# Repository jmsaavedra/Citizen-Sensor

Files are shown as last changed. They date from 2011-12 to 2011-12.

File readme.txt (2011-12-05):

Citizen Sensor

http://citizensensor.cc

DIY environmental and air quality monitoring. Has been developed as both stationary and mobile units. 

Stationary units have been deployed all over world. CS was used in the "weather tunnel" project, exhibited at the national art museum of China, Beijing summer 2011. 

*stationary*
 > operate as stationary units connected to the internet via ethernet cable
 > arduino based
 > require wall power (7-12v DC power brick)
 > use pachube (some units live currently: https://pachube.com/feeds?user=weathertunnel)
 > schematic on Upverter: http://upverter.com/jmsaavedra/634b5640a5bbd8a7/Citizen-Sensor---Stationary-Version-02/

*mobile*
 > operate as bluetooth peripherals for an Android application
 > arduino based
 > battery powered
 > updates output to LAYAR, google maps, and private social networks
 > pachube support coming

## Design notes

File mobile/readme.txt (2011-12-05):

Citizen Sensor

http://citizensensor.cc

DIY environmental and air quality monitoring. Has been developed as both stationary and mobile units. 

*mobile*
 > operate as bluetooth peripheral for an Android application
 > arduino based
 > battery powered
 > updates output to LAYAR, google maps, and private social networks
 > pachube support coming

Arduino + Bluetooth antenna talks to Android phone.  Android phone beams data up to custom server.

coming: - schematics / board design
	- Android app
	- arduino compatible circuit code

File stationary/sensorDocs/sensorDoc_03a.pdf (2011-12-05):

Weather

Tunnel

:

Sensor

Data

sheet
>>

Technology

Overview

and

Data

Schematic

Each

Weather

Tunnel

collaborator

will

be

setting

up

their

own

local

data

collection
‘node’,

feeding

and

sharing

local

environmental

data

for

use

by

all

other

institutions.
In

order

to

do

this,

we’ll

be

utilizing

custom

hardware

and

software.

This

document
will

provide

an

overview

as

to

how

we

will

be

capturing,

sharing,

and

accessing

all
data.

Hardware

Each

collaborator

will

receive

a

Weather

Tunnel

sensor

module.

These

boxes

are
meant

to

be

placed

outside,

however

there

are

several

considerations

to

be

made
before

installation.

The

sensor

module

requires

access

to

two

things:

power

(110v
or

220v

is

fine)

and

a

hardline

Ethernet

connection

to

the

internet

with

a

static

IP
address.

Each

module

will

arrive

to

you

pre-‐programmed

to

connect

from

a

specific
IP

address

which

you

will

need

to

identify

(and

share

with

us,

see

‘Identifying

your
IP

Address’)

before

receiving

it.

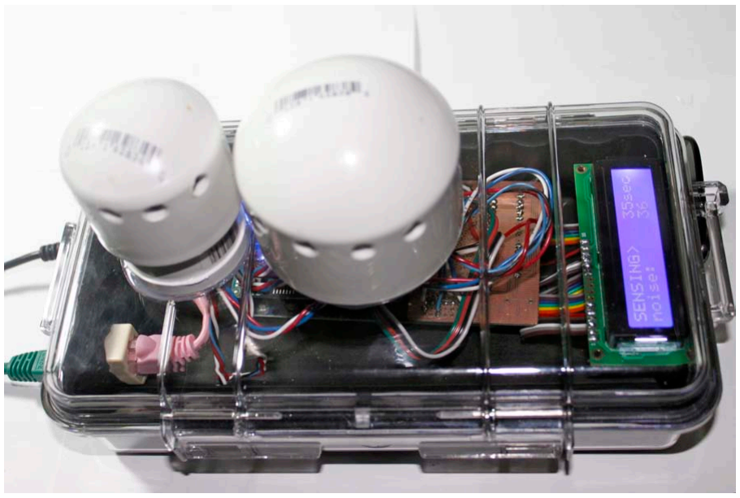
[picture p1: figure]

The

sensor

module

is

designed

to

be

installed

outdoors

and

able

to

survive
moderate

to

medium-‐heavy

rain

in

all

temperatures.

However,

if

it

is

heavily
raining

outside

your

window,

please

feel

free

to

bring

it

inside

for

that

period

of
time.

The

modules

are

outfitted

with

sensors

for

measuring:
-‐ ambient

light
-‐ ambient

sound
-‐ temperature
-‐ humidity
-‐ carbon

monoxide

(CO)
-‐ carbon

dioxide

(CO2)
-‐ general

air

quality

(NOx,

smoke)

The

sensors

themselves

are

located

beneath

two

PVC

dome

shields.

The

smaller
dome

contains

temperature,

humidity,

and

ambient

noise

sensors.

The

light

sensor
is

housed

in

the

body

of

the

module.

The

remaining

gas

sensors

are

located

in

the
larger

dome.

These

are

housed

separately,

as

their

sensing

mechanism

involves
heating

a

gas-‐specific

sensitive

element.

The

heat

could

damage

the

other

sensors,
so

they

have

been

isolated.

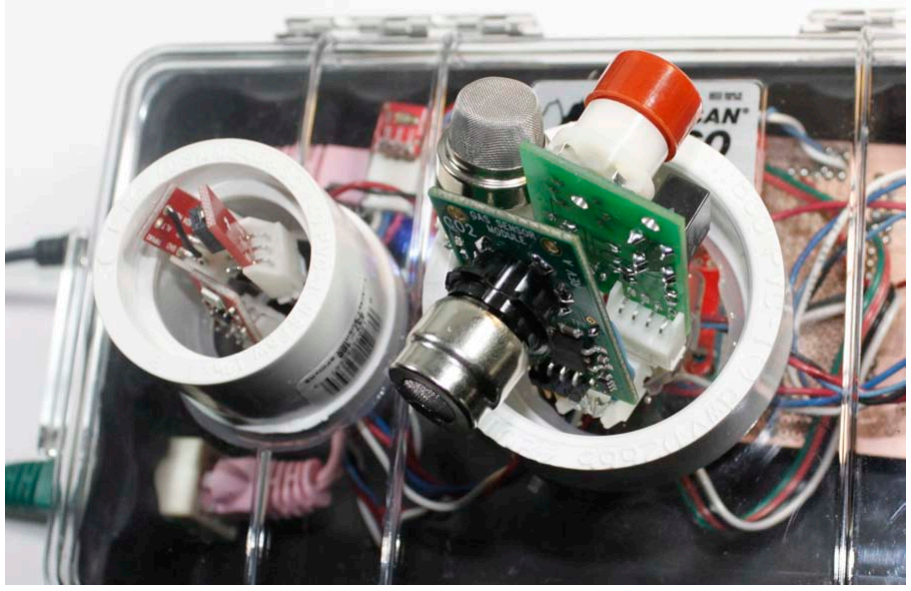
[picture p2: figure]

Each

dome

has

4

holes

for

air

to

enter

and

flow

through.

A

mesh

has

been

adhered
to

the

inside

of

the

holes

to

prevent

large

particles

of

moisture

or

debris

to

enter

the
sensor

housing.

The

domes

are

removable

and

have

not

been

permanently
attached.

This

is

to allow

you

to

rotate

them

as

needed

so

the

holes

point

away

from
your

building,

for

instance.

Setup:

The

modules

have

been

designed

to

be

‘plug

and

play’.

Upon

receiving

yours,
simply

connect

the

Ethernet

cable

(connected

through

the

static

IP

address

you

identified

to

us

when

requesting

your

unit),

and

then

the

power

supply,

which

is
included

in

the

package

you

have

received.

The

unit

will

turn

on

and

immediately
begin

reading

it’s

sensors

and

posting

data

online.

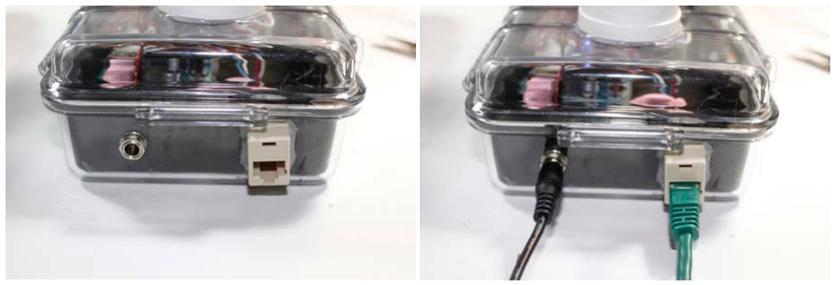
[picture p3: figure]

A

few

notes:

Once

you’ve

begun

posting

data

successfully,

it

will

take

2

–

3

days

for
all

of

your

data

to

‘normalize’.

This

is

because

several

of

the

gas

sensors

using

analog
filaments

for

sensing

pollutants.

They

require

this

amount

of

warm-‐up

time

before
they

are

stabilized.

Be

sure

to

leave

the

unit

powered

at

all

times.

It

is

also

normal
for

the

unit

to

warm

up.

Both

the

gas

sensors

as

well

as

the

body

itself

will

heat

up.
This

is

normal,

do

not

be

alarmed.

LCD

Messages:

Each

unit

is

equipped

with

an

LCD

screen

that

displays

constant
status

messages.

Here

is

a

quick

overview

of

each

message.

Upon

powering

your

unit,

you

will

be

greeted.

An

initialization

sequence

will

follow.
The

initialization

sequence

will

display

the

IP

address,

Subnet

Mask,

and

Gateway
Address

that

have

been

programmed

into

your

specific

unit.

These

must

match

the
addresses

of

the

specific

Ethernet

port

you

have

connected

the

unit

to!

It

will

also
display

your

node’s

specific

Pachube

Feed

ID.

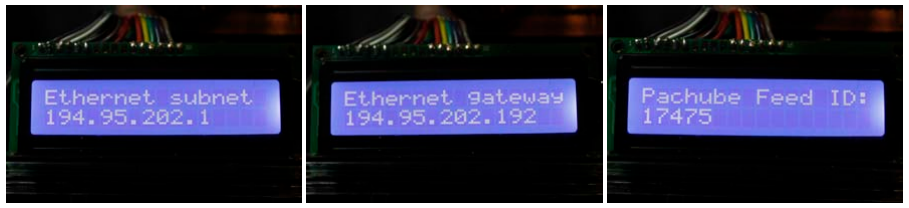
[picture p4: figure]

This

initialization

sequence

will

display

each

time

the

unit

has

been

powered

or
reset.

Following

this

setup,

the

unit

will

begin

reading

data

from

the

sensors.

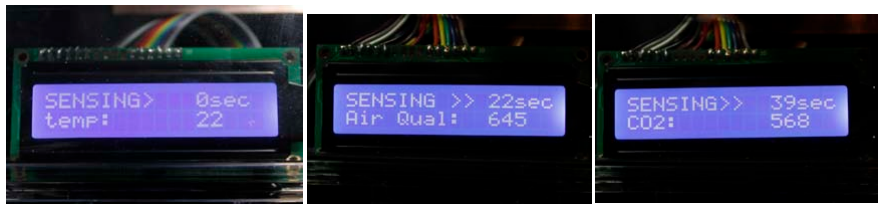
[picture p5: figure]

While

the

unit

is

taking

measurements,

it

will

display

“SENSING

>>”

in

the

top

left
corner.

On

the

right

side

of

the

top

line

is

the

number

of

seconds

that

have

passed
since

the

last

successful

data

upload.

This

number

will

never

go

above

120sec.

On
the

second

line

you’ll

see

the

sensor

being

read

at

that

moment.

To

the

right

of

this,
the

value

of

the

reading

taken

at

that

moment.

During

this

time,

a

blue

LED

will

be
pulsing

on

and

off

letting

you

know

from

a

distance

that

sensors

are

being
measured.

Every

30-‐40

seconds,

the

unit

will

attempt

to

upload

the

latest

readings.

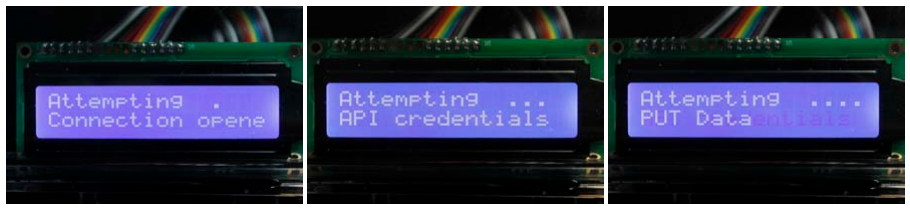
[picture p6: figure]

These

messages

are

mostly

for

debugging

purposes.

The

display

will

update

as

the
unit

goes

through

each

step

of

connecting

to

the

Pachube

server.

If

all

is

well,

these
should

cycle

quickly.

If

the

connection

attempt

was

successful

you

will

see

the
message

“Data

Sent!”

on

the

screen.

The

unit

will

now

return

to

reading

the

sensors.

If

there

were

problems

during

the

upload

process,

you

will

see

the

message
“Connection

Fail

check

IP/subnet/gateway”.

If

the

connection

fails

repeatedly

and
no

successful

upload

has

been

made

in

over

2

minutes,

the

board

will

reset

itself.

If
you

notice

that

the

board

is

never

able

to

connect,

and

simply

resets

itself
repeatedly,

please

read

the

troubleshooting

section.

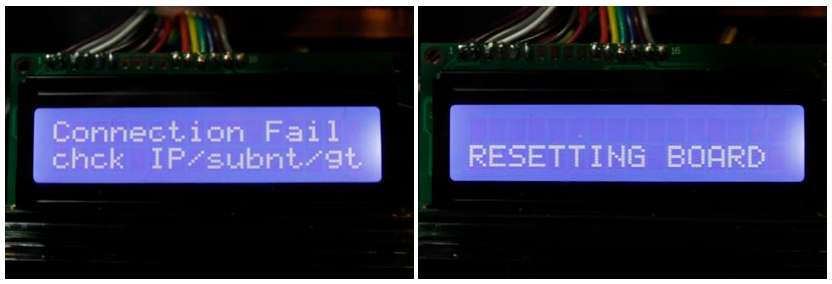
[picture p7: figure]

Troubleshooting:

If

your

unit

seems

unable

to

make

any

connection

at

all

with

the
server,

the

problem

is

most

likely

with

the

addresses

programmed

into

the

unit.

1. Unplug

the

power

supply

from

the

unit,

and

then

replug.

This

resets

the
microcontroller

and

will

allow

you

to

see

what

addresses

the

unit

is
attempting

to

use.
2. Make

a

note

of

the

three

addresses

displayed

on

the

LCD

screen

as

the

unit
powers

up

(IP,

subnet,

gateway).
3. Disconnect

the

unit

from

the

Ethernet

port.
4. Connect

a

laptop

to

the

internet

through

the

very

Ethernet

port

the

unit

was
previously

connected

to.
5. Once

connected

to

the

internet,

compare

the

addresses

used

by

your
computer

to

those

noted

from

the

unit.
6. If

they

are

identical

addresses,

the

problem

is

physical.

Perhaps

the

Ethernet
coupler

in

the

box

has

become

loose.

Or

perhaps

something

in

the

box

has
died.

Email

Joe

(saavedra@jos.ph)

and

describe

the

situation,

it

is

possible

a
replacement

is

needed.
7. If

the

addresses

are

different,

email

Joe

and

describe

the

situation.

It

is
indeed

possible

for

you

to

reprogram

the

unit

with

the

correct

addresses,
however

it

will

require

about

20

minutes

of

your

time

(assuming

no
experience

with

Arduino),

and

a

computer.

Identifying

your

static

IP

address:

Once

you’ve

found

a

window

that

is

suitable
(near

an

Ethernet

internet

connection

and

power

outlet),

you’ll

need

to

send

us

that
specific

IP

address,

Subnet

Mask,

and

Gateway

(if

applicable)

so

we

may

program
your

unit

properly

before

sending

it

to

you.

This

is

very

simple.

Connect

a

computer
to

this

port

and

make

sure

you

are

able

to

go

online.

Then,

in

OS

X,

navigate

to
System

Preferences

>

Network

and

select

the

Ethernet

connection

you

are

plugged
in

to.

Then

simply

take

note

of

and

send

us

the

following

information:

Note: If

you

know

you

are

behind

a

firewall,

we

also

need

the

Gateway

address
through

which

you

can

connect.

Pachube

So,

you’re

unit

is

plugged

in

and

has

a

glowing

blue

LED

and

the

LCD

screen

is
reading

“sensing…”

and

periodically

flashing

“data

sent!”.

This

is

an

excellent

sign.
But

where

is

this

data

going?

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
this,

we

are

using

an
amazing

online

tool

called

Pachube.

Visit

Pachube.com

to

jump

in.

Each

“node”

will

have

it’s

own

Pachube

feed

to

which

it

will

be

posting

live

data.

You
can

see

all

of

Weather

Tunnel’s

nodes

by

visiting:
http://www.pachube.com/users/weathertunnel/feeds You

can

find

your

feed

in

this

list,

and

view

your

data

online

here.

Your

unit

will

update

data

approximately

every

30

seconds,

and

this

is

visible

in

the
line

graphs

on

the

right

side

of

the

feed

page.

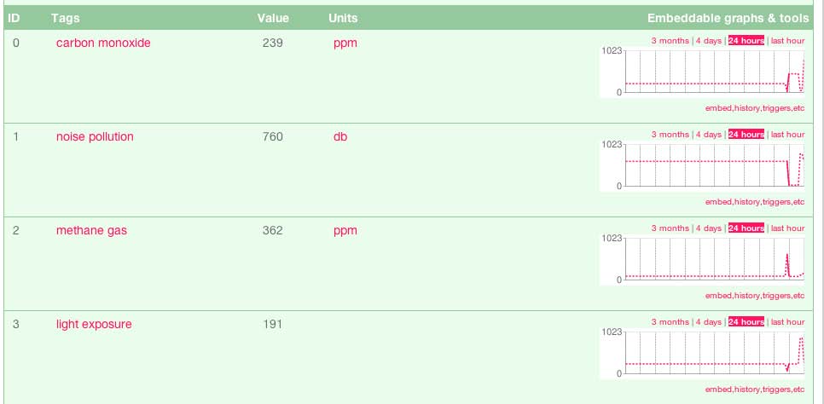
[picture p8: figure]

Pulling

data

from

Pachube

Pachube

is

an

excellent

tool

because

it

has

a

very

well

documented

and

versatile

API
with

data

available

as

XML,

CSV,

or

JSON

feeds.

You

can

read

about

the

API

here:
http://api.pachube.com/

Using

the

Pachube

API,

it

is

very

easy

to

begin

writing

live

applications

that

pull

data
any

number

of

feeds

in

real-‐time.

We

encourage

you

to

use

data

from

as

many

nodes
as

possible

in

your

piece.

All

feeds

and

necessary

API

access

info

will

be

available

on
the

Weather

Tunnel

blog

as

nodes

around

the

world

begin

to

get

setup

and

running.

When

you

begin

writing

your

custom

applications

to

interface

with

Pachube,

you
will

need

an

API

key.

This

key

will

give

you

access

to

all

of

our

feeds

and

their

data
in

any

form,

in

real-‐time.

Weather

Tunnel

Pachube

API

Key:

10_57fcWGXJjGhp21d1yJdYd--9DaXx2oYpjQOsfdGCA

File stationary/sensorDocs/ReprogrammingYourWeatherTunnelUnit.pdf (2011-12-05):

!"#$%&$'(()*&+,%-$+."'/0"$+1-**"2+3*)/+456

7/"#+6 8+9#"*+/0"+:%;+'*<+=%>'/"+/0"+37:+#%$/+%*+/0"+?$<-)*%+@"&' !"#$%&'($')$*%'+($,&$(,-$,.$/&$012%'&,$3#4/$5'61,6,&(1,++#1$%&'(7$!"#1#$')$/&$ 8("#1&#($)"'#+2$,&$(,-$,.$("')9$/&2$/$-1,(,(:-'&4$)"'#+2$,&$(,-$,.$("/(7$;&$("#$1#/1$,.$ ("#$3#4/$')$/$6%)(,5$<=#/("#1$(%&&#+$)"'#+2>$?$/$@AB$=#$2#)'4&#2$.,1$("#$CAD$ )61##&$/&2$#E(1/$)#&),1)7
!"#$6/)#$')$/$@#+'6/&$3'61,$FGHG9$/&2$,-#&$#/)'+:$,&$,&#$+,&4$)'2#7$0.(#1$,-#&'&49$ 2')6,&&#6($("#$8("#1&#($6/*+#$I-'&J$'&$("')$'5/4#K$.1,5$#'("#1$-,1(7$$L"#&$("#$6/)#$ ')$,-#&#29$("#$012%'&,$='++$1/')#$%-$,..$("#$.+,,1$,.$("#$*/)#9$)'(('&4$,&$'(M)$)'2#$?$2,$ &,($*#$/+/15#29$("')$')$&,15/+N

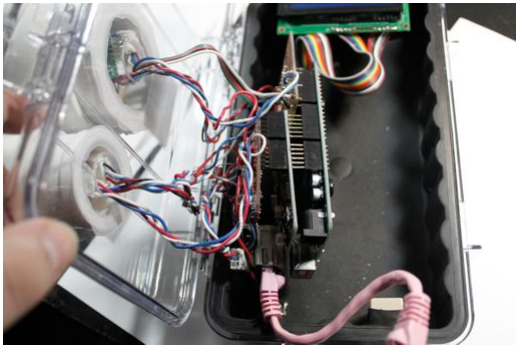
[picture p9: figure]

!"#$OPB$-,1($')$+,6/(#2$/($("#$*,((,5$,.$("#$%&'(9$2'1#6(+:$*#&#/("$("#$8("#1&#($-,1(9$ ="'6"$"/)$/$Q#1:$)",1($8("#1&#($6/*+#$6,&&#6('&4$'($(,$/$6,%-+#1$#5*#22#2$'&$("#$ 6/)#7
7/"#+A 8+B2-&+)*+37:+C'D2"+'*<+C%**">/+/%+C%(#-/"$ R#E($:,%$='++$'&)#1($("#$OPB$6/*+#$'&(,$("#$012%'&,7$$!"')$6/&$),5#('5#)$*#$/$*'($ (1'6J:9$2,&M($*#$/.1/'2$(,$-%++$("#$012%'&,$'&$("#$2'1#6(',&$&##2#2$(,$4#($#&,%4"$ /66#))$(,$("#$OPB$-,1(7

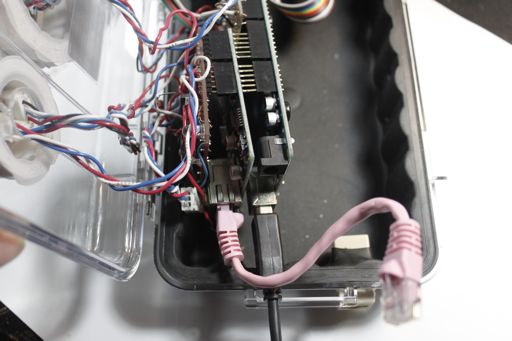
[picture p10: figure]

P(/&2/12$OPB$0$(,$B$6/*+#$6,&&#6(#2$.1,5$012%'&,$(,$3/6$,1$@A7
7/"#+E 8+F)G>%**">/+!H7H1+I"'/-$" !"#$012%'&,$8("#1&#($P"'#+2$"/)$/$(#&2#&6:$(,$"/&4$'(M)$6,&&#6(',&$="#&$*#'&4$ -,=#1#2$.,1$+,&4$-#1',2)$,.$('5#7$!"')$=/)$(1,%*+#),5#$.,1$%)9$/)$=#$=/&($("#$%&'()$ (,$*#$-,=#1#2$/&2$6,&&#6(#2$.,1$)#Q#1/+$5,&(")$)(1/'4"($I/($+#/)(K7$!"#$.'E$')$(,$ S8P8!$("#$#&('1#$%&'(7$$T,1$("')9$=#MQ#$'5-+#5#&(#2$/$)5/++$"/6J$'&$="'6"$=#$%)#$/$ 2'4'(/+$-'&$(,$S8P8!$("#$*,/12$="#&$'($"/)&M($*##&$/*+#$(,$5/J#$/$6,&&#6(',&$/.(#1$ )#Q#1/+$5'&%(#)7$
U,=#Q#19$'&$,12#1$(,$-1,41/5$("#$*,/129$=#$&##2$(,$2')6,&&#6($("')7$ V$"/Q#$+/*#+#2$ ("#$6,&&#6(',&$*:$6,+,1'&4$("#$="'(#$='1#$='("$*+/6J$<)(1'-#)>$?$5,1#$+'J#$2,()$,1$ 2/)"#)$5/2#$='("$/$)"/1-'#$5/1J#17$

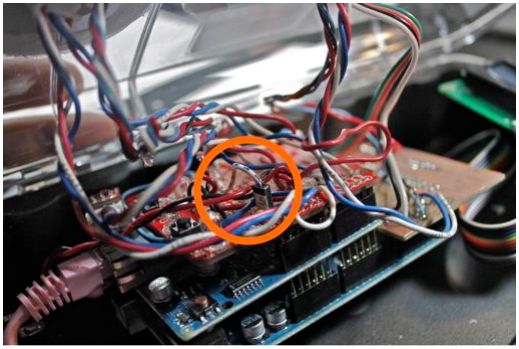
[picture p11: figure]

@%++$("#$5/1J#2$='1#$,%($,.$("#$.#5/+#$"#/2#1$-'&$/&2$+#/Q#$'($2')6,&&#6(#2$="'+#$ -1,41/55'&47

7/"#+J 8 B$%&$'(+/0"+?$<-)*% V&$,12#1$(,$-1,41/5$("#$012%'&,$:,%$='++$&##2$(,$.'1)($2,=&+,/2$/&2$'&)(/++$("#$ 012%'&,$/--+'6/(',&$="'6"$:,%$6/&$.'&2$/(N$"((-NWW/12%'&,766W#&W3/'&WP,.(=/1# 0.(#1$'&)(/++'&4$("#$/--+'6/(',&9$:,%$='++$&##2$(,$'&)(/++$/$)'&4+#$+'*1/1:$=#$/1#$%)'&4$ .,1$,&#$,.$("#$)#&),1)7$V($')$("#$APX3YZ$+'*1/1:7$$!"')$='++$*#$)#&($(,$:,%$='("$:,%1$ ),%16#$6,2#7$V&$;P[9$'($')$Q#1:$)'5-+#N$-+/6#$("#$.,+2#1$'&$!"#$%&'()#*!+$,$-./(0*&$,$ 102.3.0#+$.,+2#17$3,1#$'&.,15/(',&$,&$("')$"#1#N$ "((-NWW===7/12%'&,766W#&WU/6J'&4WC'*1/1'#) R,=$:,%$6/&$,-#&$:,%1$)J#(6"$I)#&($(,$:,%$*:$\,#K$/&2$%-+,/2$(,$("#$*,/127$$ S#5#5*#1$(,$)#+#6($("#$6,11#6($P#1'/+$@,1(9$/)$=#++$/)$-./(0*&$4#53$6789 %&2#1$ :&&1+$,$;&3./$*#.,1#$%-+,/2'&47 V.$:,%$)##$<D,&#$O-+,/2'&4>$'&$:,%1$6,&),+#9$:,%$/1#$.'&')"#2]

7/"#+J 8 !">%**">/+/0"+!H7H1+K"'/-$"+'*<+H/0"$*"/+C'D2" B#$)%1#$(,$'&)#1($("#$5/1J#2$="'(#$='1#$*/6J$'&(,$("#$.#5/+#$"#/2#1$-'&7$$R##2+#$ &,)#$-+'#1)$6/&$*#$"#+-.%+$'&$41/**'&4$'($/&2$-%)"'&4$'($'&$/++$("#$=/:7$A,&&#6($("#$ 8("#1&#($6/*+#$(,$*,("$("#$*,/12$/&2$("#$6,%-+#17

7/"#+L+8 C2%G"+/0"+3*)/+'*<+1"G/M ^,%M1#$&,=$.'&')"#27$A/1#.%++:$6+,)#$("#$*,E7$$;&$),5#$,.$("#$%&'()9$("#$1/'&*,=$='1#$ 6,&&#6('&4$("#$CAD$)61##&$&##2)$(,$*#$.,+2#2$/$*'($/&2$-%)"#2$%&2#1$("#$)61##&$ '()#+.9$,("#1=')#$'($6/&$-%($-1#))%1#$,&$("#$(,-$,.$("#$)61##&7$R,($/$"%4#$2#/+9$_%)($ ),5#("'&4$(,$+,,J$.,1$/)$:,%$6+,)#$("#$+'27

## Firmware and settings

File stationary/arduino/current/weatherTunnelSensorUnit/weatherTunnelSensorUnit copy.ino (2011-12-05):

/*
   ***_-_-_ weather tunnel sensor box v08 _-_-_***
 
 Circuit:
 * Ethernet shield attached to digital pins 10, 50, 51, 52, 53
 * LCD Screen on pins 49, 45, 29, 27, 25, 23 
 * LEDs: 12 (red), 13 (blue)
 * RESET pin connected to: pin 7
 
 Sensors:
 * ADMP401 ambient sound mic on    pin A0  - +3v - GND
 * TEMT6000 ambient light on       pin A2  - +5v - GND
 * humidity on                     pin A5  - +5v - GND
 * MQ-7 Carbon Monoxide sensor on  pin A8  - +5v - GND - D14
 * MG-811 Carbon Dioxide sensor on pin A14 - +9v - GND
 * MQ-135 Air Quality sensor on    pin A10 - +5v - GND
 * TMP102 Temperature sensor on    pin D20 (SDA-BLUE) - D21 (SCL-WHITE) - +3v - GND
 
 joseph saavedra
 http://jos.ph
 january 2011
 */

// institution
String institutionName = "Tester!";

// institution specific Pachube feed address
String feedAddr = "23656";  //Test: 23656

//unique ethernet shield MAC addr:  90-A2-DA-00-2D-A3
//this number can be found printed on the bottom of your Arduino
// fill in your ethernet shield's MAC address here:
byte mac[] = {  
  0x90, 0xA2, 0xDA, 0x00, 0x2D, 0x16   };


//TEST IP:        192.168.2.2
//Subnet Mask:    255.255.255.0
//Router:         192.168.2.1

//IP in Room 1100: 149.31.36.204
//Subnet Mask:        255.255.255.0
//Router:             149.31.36.1

// IP address for the controller:
byte ip[] = {  
  149, 31, 36, 204 };

// subnet mask -- if unneeded {255,255,255,0} works
byte subnet[] = {  
  255, 255, 255, 0  };

// router address -- if unneeded {192,168,1,1} works
byte gateway[] = {  
  149, 31, 36, 1  };	

//  Pachube server address:
byte server[] = {
//  209,40,205,190}; //THIS IS THE OLD ADDRESS
  173,203,98,29}; //THIS IS THE NEW PACHUBE ADDRESS!

#include <SPI.h>
#include <Ethernet.h>
#include <LiquidCrystal.h>
#include <Wire.h>
#include <CS_MQ7.h>

LiquidCrystal lcd(49, 45, 29, 27, 25, 23);

CS_MQ7 MQ7(14, 6); //Citizen Sensor MQ-7 Carbon Monoxide Breakout instance
int CoPrev = 0; //for storing CO Data

Client client(server, 80);

long lastConnectionTime = 0;        // last time you connected to the server, in milliseconds
boolean lastConnected = false;      // state of the connection last time through the main loop
const int postingInterval = 30000;  //delay between updates to Pachube.com, in milliseconds
const int softwareResetPin = 7; //connect this pin to RESET pin
const long int resetInterval = 120000; //if no successful connection has been made in 2 min, RESET board

void setup() {
  digitalWrite(softwareResetPin, HIGH); //softwareReset hack
  pinMode(softwareResetPin, OUTPUT);  //softwareReset hack
  Serial.begin(9600);
  Serial.println("start setup");
  lcdSetup();
  Ethernet.begin(mac, ip);
  lcdEthernet(ip, subnet, gateway, feedAddr);
  Wire.begin();
  lastConnectionTime = millis();
  Serial.println("end setup");
  delay(1000);
  setupLedFlash();
  lcd.clear();
}

void loop() {
  Serial.println("Reading Sensors...");
  lcd.clear();
  String dataString = " "; //will hold all sensor data

  // read the sensors:
  Serial.println("sensor 0 - temperature..."); //temperature
  int sensor0_reading = 0;
  sensor0_reading = getTemperature();
  dataString = String(sensor0_reading);
  lcdUpdater(0, sensor0_reading);
  Serial.println(dataString);

  Serial.println("sensor 1 - light..."); //light
  int sensor1_reading = 0;
  sensor1_reading = getLight();
  dataString += ",";
  dataString = dataString + String(sensor1_reading);
  lcdUpdater(1, sensor1_reading);
  Serial.println(dataString);

  Serial.println("sensor 2 - humidity..."); //humidity
  int sensor2_reading = getHumidity();
  dataString += ",";
  dataString = dataString + String(sensor2_reading);
  lcdUpdater(2, sensor2_reading);
  Serial.println(dataString);

  Serial.println("sensor 3 - noise..."); //noise
  int sensor3_reading = getNoise();
  dataString += ",";
  dataString = dataString + String(sensor3_reading);
  lcdUpdater(3, sensor3_reading);
  Serial.println(dataString);

  Serial.println("sensor 4 - CO2..."); //CO2
  //int sensor4_reading = analogRead(8);
  int sensor4_reading = getCO2();
  dataString += ",";
  dataString = dataString + String(sensor4_reading);
  lcdUpdater(4, sensor4_reading);
  Serial.println(dataString);

  Serial.println("sensor 5 - CO..."); //CO
  //int sensor4_reading = analogRead(10);
  int sensor5_reading = getCO();
  dataString += ",";
  dataString = dataString + String(sensor5_reading);
  lcdUpdater(5, sensor5_reading);
  Serial.println(dataString);

  Serial.println("sensor 6 - Air Qual..."); //Air Quality
  //int sensor4_reading = analogRead(10);
  int sensor6_reading = getAirQual();
  dataString += ",";
  dataString = dataString + String(sensor6_reading);
  lcdUpdater(6, sensor6_reading);
  Serial.println(sensor6_reading);

  //if we have passed the timer interval set for posting (3000ms), 
  //then send data!
  if(millis() - lastConnectionTime > postingInterval){
    Serial.println("sendData!");
    if(millis() - lastConnectionTime > resetInterval){
      softwareReset(); //RESET ENTIRE BOARD
    }
    else{
      sendData(dataString);
    }
  }
  // store the state of the connection for next time through
  // the loop:
  lastConnected = client.connected();
  Serial.println("... end of loop ...");
}


// make an HTTP connection to the server:
void sendData(String thisData) {
  lcd.clear();
  lcd.setCursor(0,0);
  lcd.print("Attempting ");
  lcd.setCursor(0,1);
  lcd.print("Connect and Send");
  // if there's a successful connection:
  if (client.connect()) {
    Serial.println("connecting...");
    lcd.setCursor(12,0);
    lcdConnect();
    lcdStatusBar();

    // send the HTTP PUT request. 
    lcdPUT();
    client.print("PUT /api/"+feedAddr+".csv HTTP/1.1\n");
    lcdStatusBar();

    lcdPachubeConnect();   
    client.print("Host: www.pachube.com\n");
    // weather tunnel API key: mFgy2cgsyv4GKhw4G4EzNcpgpfhQJkg4JvCrNpOskwo
    client.print("X-PachubeApiKey: mFgy2cgsyv4GKhw4G4EzNcpgpfhQJkg4JvCrNpOskwo\n");
    client.print("Content-Length: ");
    client.println(thisData.length(), DEC);
    lcdStatusBar();

    // last pieces of the HTTP PUT request:
    client.print("Content-Type: text/csv\n");
    client.println("Connection: close\n");

    // here's the actual content of the PUT request:
    lcdDataPUT();
    client.println(thisData);
    lcdStatusBar();

    lcd.clear();
    lcd.setCursor(0,0);
    lcd.print("   Data Sent!   ");
    flashGreenLED();
    // note the time that the connection was made:
    lastConnectionTime = millis();

    Serial.println();
    Serial.println("disconnecting.");
    client.stop();
  } 
  else {
    // if you couldn't make a connection:
    lcdConnectionFail();
  }
}

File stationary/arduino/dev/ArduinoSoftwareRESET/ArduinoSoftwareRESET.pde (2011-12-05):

//digitalPin 7 is connected to the RESET pin on Arduino
//NOTE: you CANNOT program the board while they are connected
//by default digitalPin 13 will blink upon reset, so stick an LED in there

int interval = 5000;
long int time = 0;

void setup(){
  digitalWrite(7, HIGH); //We need to set it HIGH immediately on boot
  pinMode(7,OUTPUT);     //We can declare it an output ONLY AFTER it's HIGH
                         // (( HACKHACKHACKHACK ))
  Serial.begin(9600);    //So you can watch the time printed
}


void loop(){

  time = millis();
  
  Serial.println(time);
  
  if(time > interval){
    Serial.println("RESET!");
    digitalWrite(7, LOW); //Pulling the RESET pin LOW triggers the reset.
  }
}

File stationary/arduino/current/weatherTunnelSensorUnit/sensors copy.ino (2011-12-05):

//the number of readings to be taken for averaging
//analog sensors, each time they are called
#define NUMREADINGS 25
//debounce time
#define DEBOUNCETIME 10

//---------- temperature ----------
int getTemperature(){
  byte tmp102comm = Wire.requestFrom(72,2); 
  if (tmp102comm == 2) {
    byte msb = Wire.receive(); /* Whole degrees */
    byte lsb = Wire.receive(); /* Fractional degrees */
    int val = ((msb) << 4);   /* MSB */
    val |= (lsb >> 4);    /* LSB */
    float celsius = (val*0.0625)-5;
    float farenheit = (celsius*1.8) + 32;
  /*Serial.print("C: ");
    Serial.println(celsius);
    Serial.print("F: ");
    Serial.println(farenheit);
    Serial.println();
    delay(1000);*/ 
    return int(celsius);
  }
}

//---------- light ----------
int getLight(){
  int lightVal = 0;
  lightVal = analogRead(2);
  delay(DEBOUNCETIME);
  return lightVal;    
}

//---------- humidity ----------
int getHumidity(){
  int humidityVal = 0;
  for(int i=0; i<NUMREADINGS; i++){
    int tempRead = analogRead(5);
    humidityVal = humidityVal + tempRead;
    delay(DEBOUNCETIME);
  }
  humidityVal = humidityVal/NUMREADINGS;    
  return humidityVal;   
}

//---------- ambient noise ----------
int getNoise(){
  int noiseVal = 0;
  int ctr = 0;
  int nAverage = 0;
  for(int i = 0; i< NUMREADINGS-10; i++){
    int tempRead = analogRead(A0);
    if(tempRead > 0){
      tempRead = abs(tempRead - 300);
      noiseVal = noiseVal + tempRead;
      ctr++;
      delay(DEBOUNCETIME);
    }
  }
  noiseVal = noiseVal/ctr;
  return noiseVal;
}

//---------- carbon dioxide ----------
int getCO2(){
  int CO2Val = 0;
  for(int i=0; i<NUMREADINGS; i++){
    int tempRead = analogRead(14);
    CO2Val = CO2Val + tempRead;
    delay(DEBOUNCETIME);
  }
  CO2Val = CO2Val/NUMREADINGS;
  CO2Val = 1000 - CO2Val; // sensor returns lower value the more CO2 is detected
  return CO2Val;    
}

//---------- air quality ----------
int getAirQual(){
  int AirQualVal = 0;
  for(int i=0; i<NUMREADINGS; i++){
    int tempRead = analogRead(10);
    AirQualVal = AirQualVal + tempRead;
    delay(DEBOUNCETIME);
  }
  AirQualVal = AirQualVal/NUMREADINGS;  
  return AirQualVal;    
}

//---------- carbon monoxide ----------
int getCO(){
  pinMode(14, OUTPUT);

  MQ7.CoPwrCycler();  

  if(MQ7.CurrentState() == LOW){   //we are at 1.4v, read sensor data!
    int CoData = 0;
    for(int i=0; i<NUMREADINGS; i++){
      int tempRead = analogRead(8);
      CoData = CoData + tempRead;
      delay(DEBOUNCETIME);
    }
    CoData = CoData/NUMREADINGS; 
    CoPrev = CoData;
    return CoData;
    //Serial.println(CoData);
  }
  else{                            //sensor is at 5v, heating time
    //during heating time we cannot read new data, return previous reading:
    return CoPrev;
  }      
}

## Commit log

2012-02-12 updates for arduino 1.0
2012-03-08 updated eagle files
    [COsensor03.brd, COsensor03.sch]
